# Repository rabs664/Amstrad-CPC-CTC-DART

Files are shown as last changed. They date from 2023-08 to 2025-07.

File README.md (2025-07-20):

# Amstrad CPC CTC DART
Simple Z80 CTC and DART board compatible with the Amstrad CPC and MX4 connector

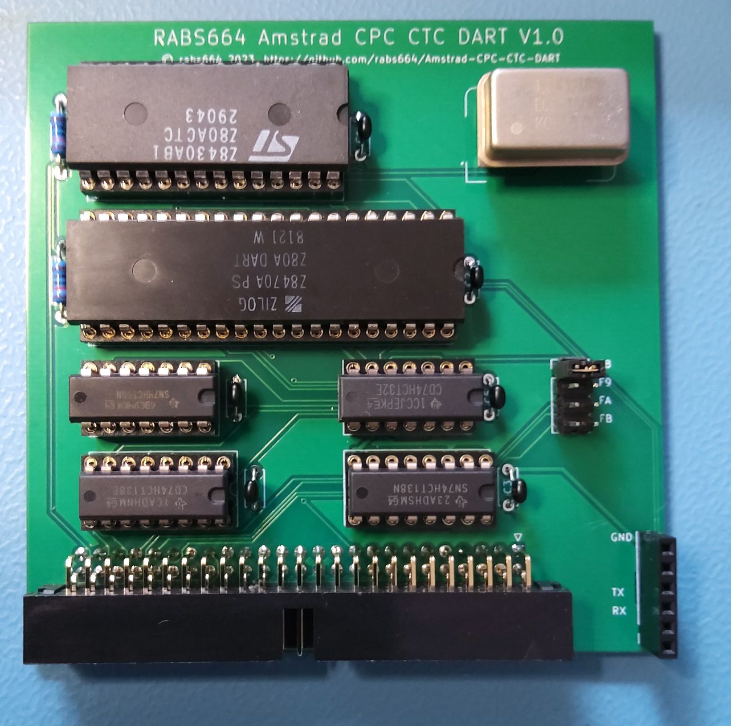
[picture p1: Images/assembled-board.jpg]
assembled-board


## Objective
Prototyping board to learn about the Z80 CTC and DART, and how to write Z80 assembly using an Amstrad CPC.

## Background
Part of a number of modular cards using Z80 associated peripherals and the Amstrad CPC.

See also;
[Amstrad CPC 2855 PIO](https://github.com/rabs664/Amstrad-CPC-8255-PIO), [Amstrad CPC Z80 CTC](https://github.com/rabs664/Amstrad-CPC-Z80-CTC) and [Amstrad CPC Z80 DART](https://github.com/rabs664/Amstrad-CPC-Z80-DART)

## Backplane
[CPC Amstrad Expansion Backplane by revaldinho](https://github.com/revaldinho/cpc_ram_expansion/wiki/CPC-Expansion-Backplane)

## IO Addressing
The IO Address can be selected using jumpers, supporting the following base address.

* F8XX
* F9XX
* FAXX
* FBXX

The CTC is then adressed at XXEO and the DART at XXF0.

See [CPC Wiki IO Port Summary](https://www.cpcwiki.eu/index.php/I/O_Port_Summary) for a list of known IO ports used on the Amstrad CPC.

## Testing
The CTC DART board has been built and simple testing has been completed on an Amstrad CPC 6128.

Note also an FTDI Serial Adapter was used to connect to a Tera Term session.

## PCBs
PCBs are available from [Seeed Studio](https://www.seeedstudio.com/Amstrad-CPC-CTC-DART-V1-0-g-1398289).

## Components
This [Digi-Key](https://www.digikey.co.uk/en/mylists/list/81SQJULUKE) List contains all components excluding the Z80 CTC, DART and FTDI Serial Adapter.

## Assembler
[RASM](https://github.com/EdouardBERGE/rasm)

## Resources
[CPCWiki](https://www.cpcwiki.eu/index.php/Main_Page)

Z80 Application by James W Coffron ISBN 0-89588-094-6

## Acknowledgements
[@revaldinho](https://github.com/revaldinho)

Don Prefontaine 

Peter Murray

[@EdouardBERGE](https://github.com/EdouardBERGE)

[@johnwinans](https://github.com/johnwinans)

# Release History
## Version 1.0
* First Release

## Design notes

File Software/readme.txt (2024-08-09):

This folder contains software associated with the Amstrad CPC CTC DART.

* siolif01.asm contains function libary associated with the DART.
* siotst10.asm contains a test program in assembler
* siotst03.bas contains a simple test program in BASIC
* siotst07.bas contains a send an receive test program in BASIC
* siotst01.dsk disk file containing siotst03.bas and siotst07.bas

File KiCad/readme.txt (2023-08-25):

This folder contains files associated with the use of KiCad 7 to create the schematics and PCB.

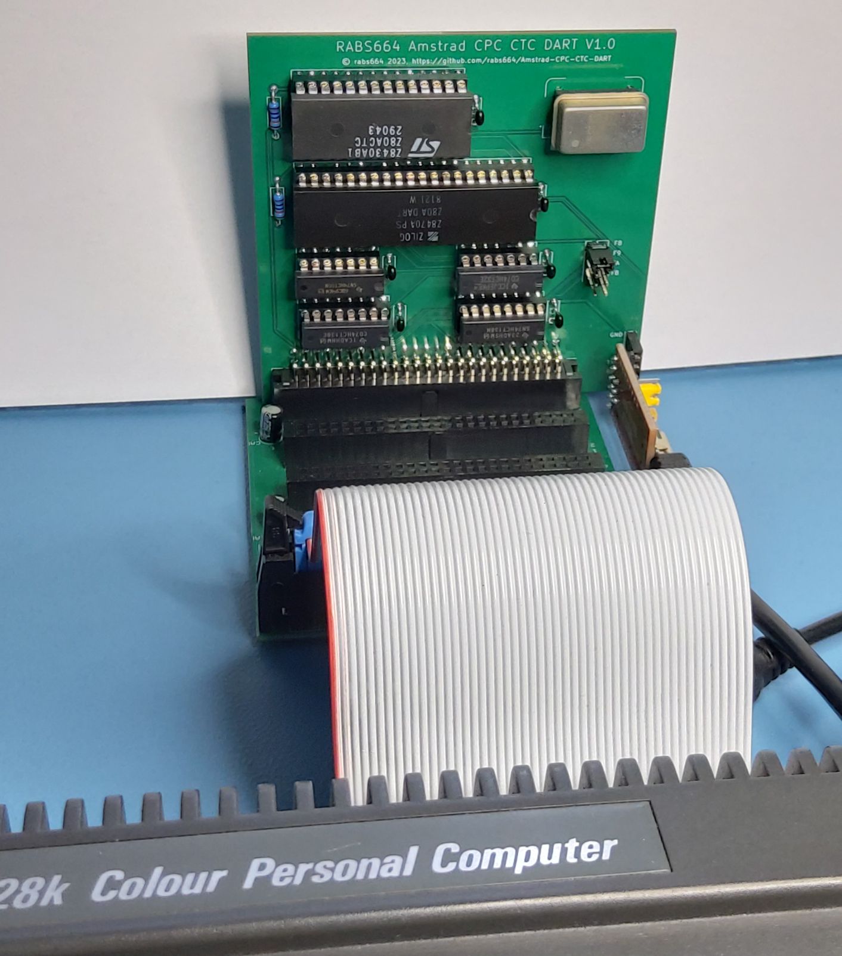
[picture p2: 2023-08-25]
Images/board-connected-CPC.jpg

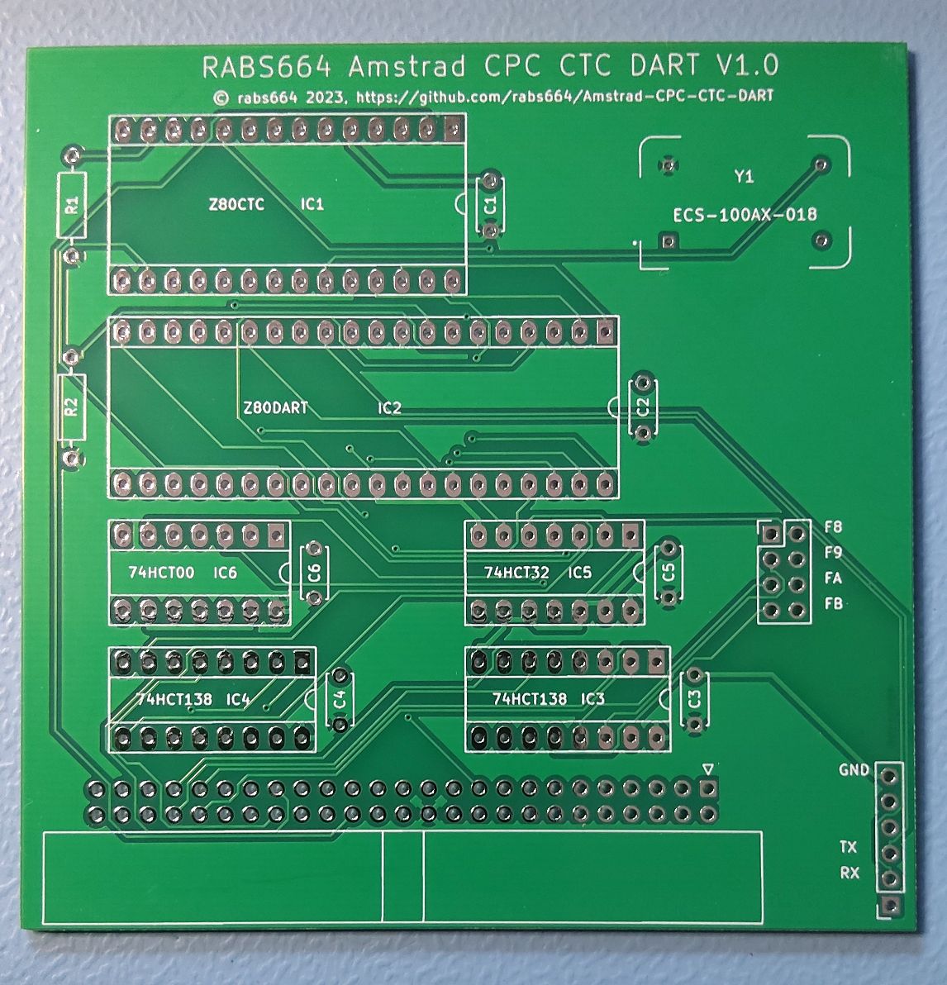
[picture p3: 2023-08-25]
Images/bare-board.jpg

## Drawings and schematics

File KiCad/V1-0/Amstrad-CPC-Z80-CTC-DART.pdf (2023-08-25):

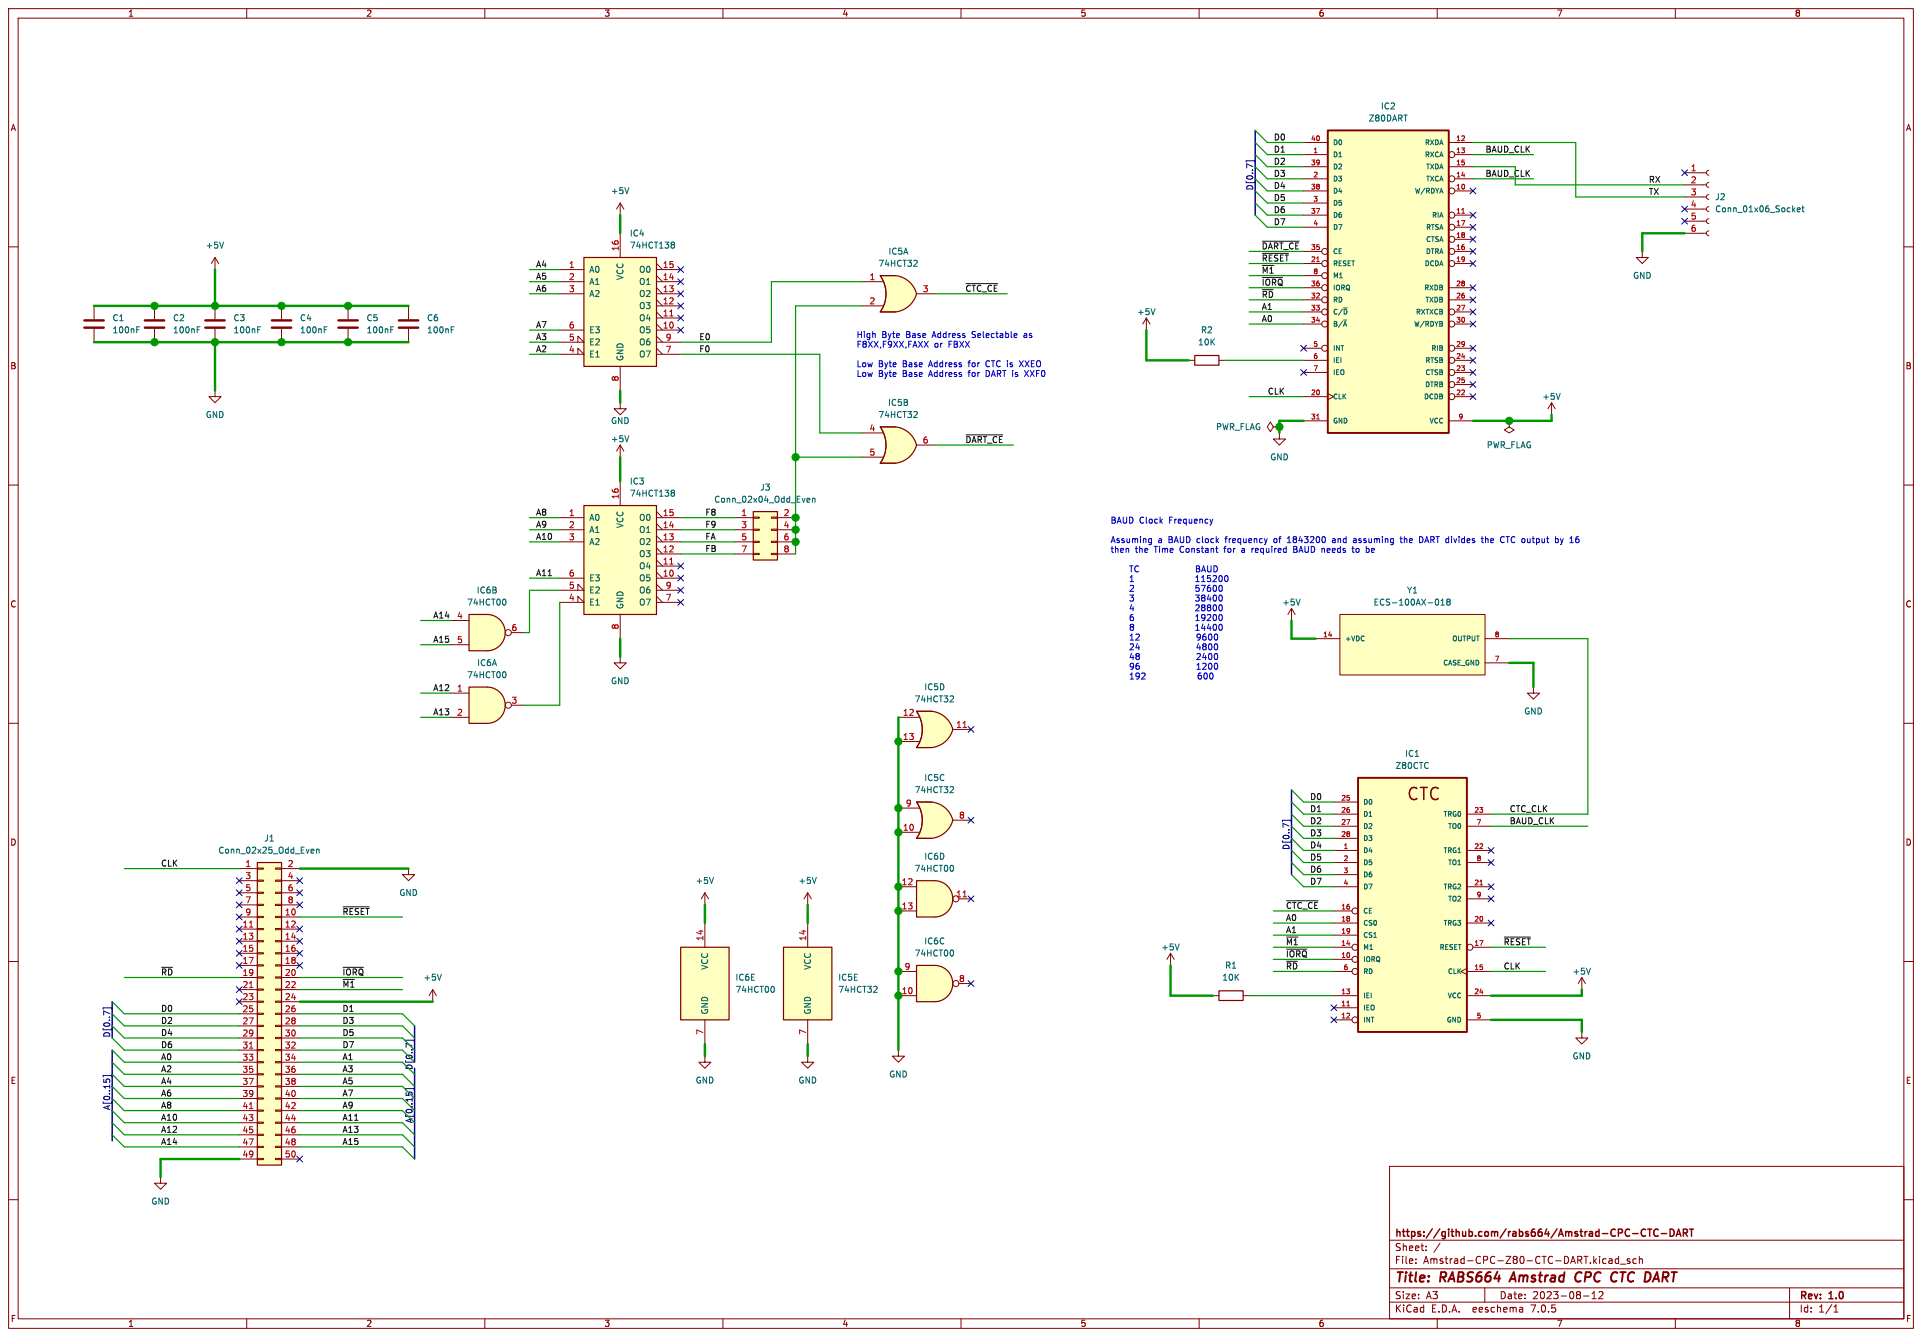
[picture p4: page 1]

Low Byte Base Address for CTC is XXEO

File: Amstrad-CPC-Z80-CTC-DART.kicad_sch Sheet: / https://github.com/rabs664/Amstrad-CPC-CTC-DART

Id: 1/1 Title: RABS664 Amstrad CPC CTC DART

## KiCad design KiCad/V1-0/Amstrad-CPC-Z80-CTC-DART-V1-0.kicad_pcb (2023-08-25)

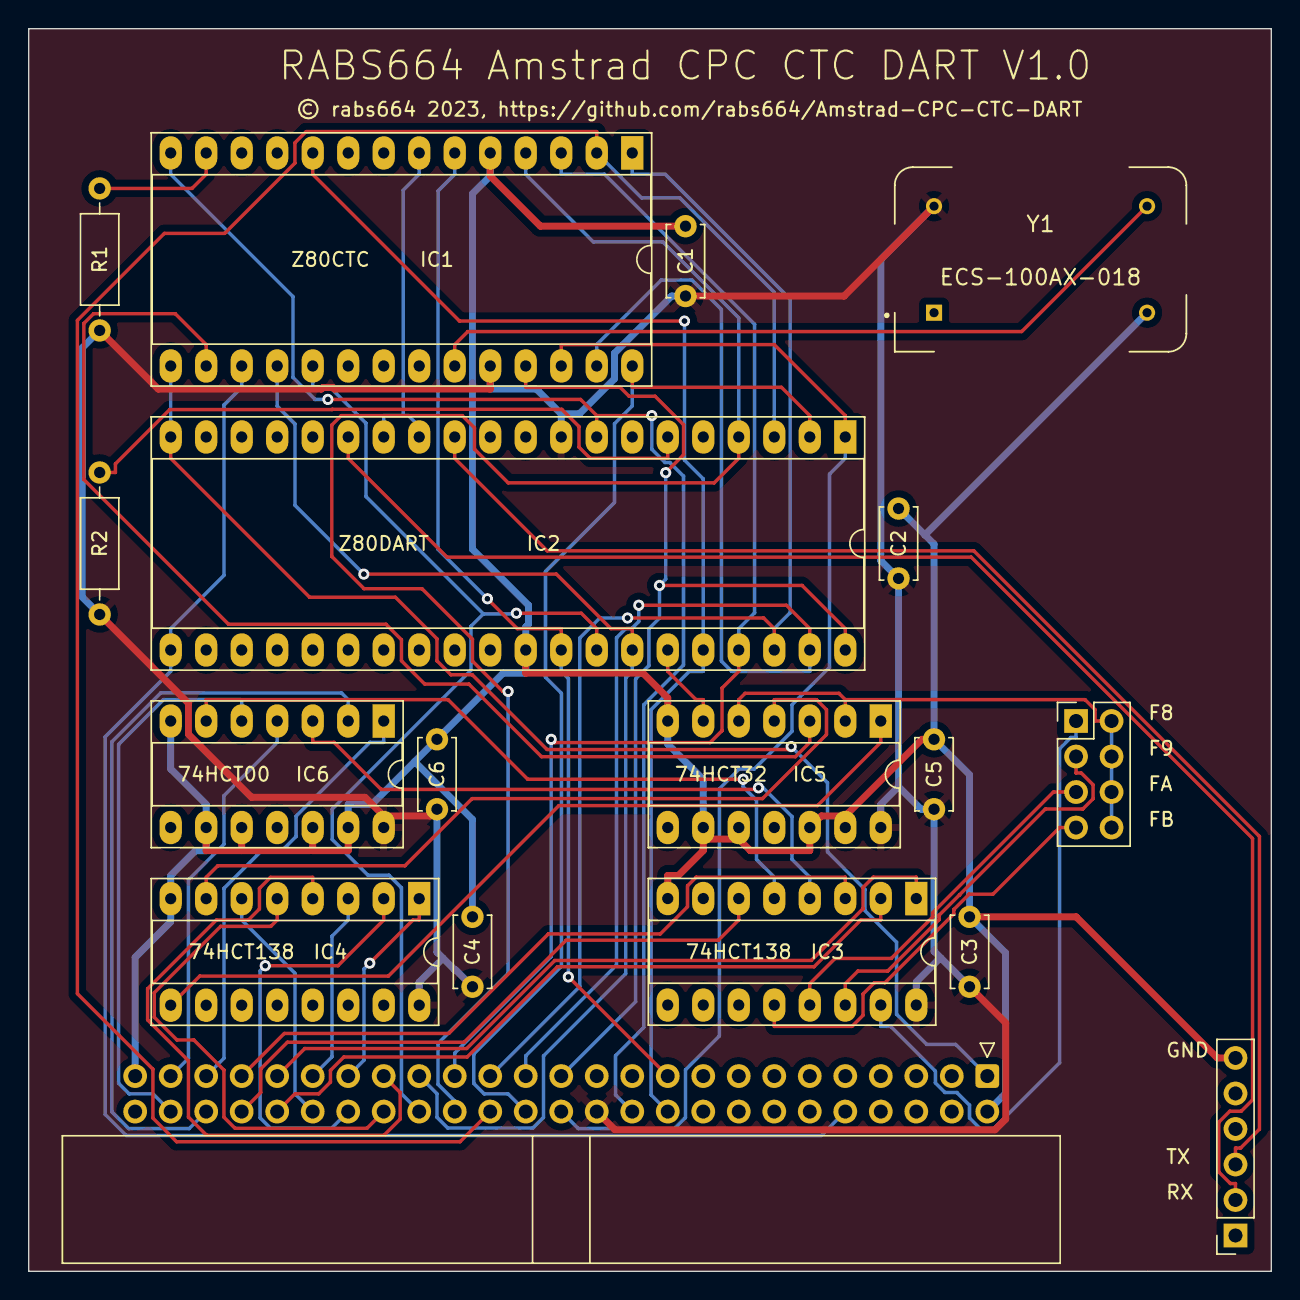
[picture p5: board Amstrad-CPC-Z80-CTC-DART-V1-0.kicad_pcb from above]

Board: 2 copper layers, 88.9 x 88.9 mm, 18 parts (0 on the bottom side), 48 nets.

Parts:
C1, C2, C3, C4, C5, C6: 100nF; C_Disc_D5.0mm_W2.5mm_P5.00mm
IC1: Z80CTC; DIP-28_W15.24mm_Socket_LongPads
IC2: Z80DART; DIP-40_W15.24mm_Socket_LongPads
IC3, IC4: 74HCT138; DIP-16_W7.62mm_Socket_LongPads
IC5: 74HCT32; DIP-14_W7.62mm_Socket_LongPads
IC6: 74HCT00; DIP-14_W7.62mm_Socket_LongPads
J1: Conn_02x25_Odd_Even; IDC-Header_2x25_P2.54mm_Horizontal
J2: Conn_01x06_Socket; PinSocket_1x06_P2.54mm_Vertical
J3: Conn_02x04_Odd_Even; PinHeader_2x04_P2.54mm_Vertical
R1, R2: 10K; R_Axial_DIN0207_L6.3mm_D2.5mm_P10.16mm_Horizontal
Y1: ECS-100AX-018; OSC_ECS-100AX-018

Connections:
+5V: C1.1, C2.1, C3.1, C4.1, C5.1, C6.1, IC1.24 (VCC), IC2.9 (VCC), IC3.16 (VCC), IC4.16 (VCC), IC5.14 (VCC), IC6.14 (VCC), J1.24, R1.1, R2.1, Y1.14 (+VDC)
/A0: IC1.18 (CS0), IC2.34 (B/~A), J1.33
/A1: IC1.19 (CS1), IC2.33 (C/~D), J1.34
/A2: IC4.4 (E1), J1.35
/A3: IC4.5 (E2), J1.36
/A4: IC4.1 (A0), J1.37
/A5: IC4.2 (A1), J1.38
/A6: IC4.3 (A2), J1.39
/A7: IC4.6 (E3), J1.40
/A8: IC3.1 (A0), J1.41
/A9: IC3.2 (A1), J1.42
/A10: IC3.3 (A2), J1.43
/A11: IC3.6 (E3), J1.44
/A12: IC6.1, J1.45
/A13: IC6.2, J1.46
/A14: IC6.4, J1.47
/A15: IC6.5, J1.48
/BAUD_CLK: IC1.7 (TO0), IC2.13 (RXCA), IC2.14 (TXCA)
/CLK: IC1.15 (CLK), IC2.20 (CLK), J1.1
/CTC_CLK: IC1.23 (TRG0), Y1.8 (OUTPUT)
/D0: IC1.25 (D0), IC2.40 (D0), J1.25
/D1: IC1.26 (D1), IC2.1 (D1), J1.26
/D2: IC1.27 (D2), IC2.39 (D2), J1.27
/D3: IC1.28 (D3), IC2.2 (D3), J1.28
/D4: IC1.1 (D4), IC2.38 (D4), J1.29
/D5: IC1.2 (D5), IC2.3 (D5), J1.30
/D6: IC1.3 (D6), IC2.37 (D6), J1.31
/D7: IC1.4 (D7), IC2.4 (D7), J1.32
/E0: IC4.9 (O6), IC5.1
/F0: IC4.7 (O7), IC5.4
/F8: IC3.15 (O0), J3.1
/F9: IC3.14 (O1), J3.3
/FA: IC3.13 (O2), J3.5
/FB: IC3.12 (O3), J3.7
/RX: IC2.15 (TXDA), J2.2
/TX: IC2.12 (RXDA), J2.3
/~CTC_CE: IC1.16 (CE), IC5.3
/~DART_CE: IC2.35 (CE), IC5.6
/~IORQ: IC1.10 (IORQ), IC2.36 (IORQ), J1.20
/~M1: IC1.14 (M1), IC2.8 (M1), J1.22
/~RD: IC1.6 (RD), IC2.32 (RD), J1.19
/~RESET: IC1.17 (RESET), IC2.21 (RESET), J1.10
GND: C1.2, C2.2, C3.2, C4.2, C5.2, C6.2, IC1.5 (GND), IC2.31 (GND), IC3.8 (GND), IC4.8 (GND), IC5.7 (GND), IC5.9, IC5.10, IC5.12, IC5.13, IC6.7 (GND), IC6.9, IC6.10, IC6.12, IC6.13, J1.2, J1.49, J2.6, Y1.7 (CASE_GND)
unnamed: IC1.13 (IEI), R1.2
unnamed: IC2.6 (IEI), R2.2
unnamed: IC3.4 (E1), IC6.3
unnamed: IC3.5 (E2), IC6.6
unnamed: IC5.2, IC5.5, J3.2, J3.4, J3.6, J3.8

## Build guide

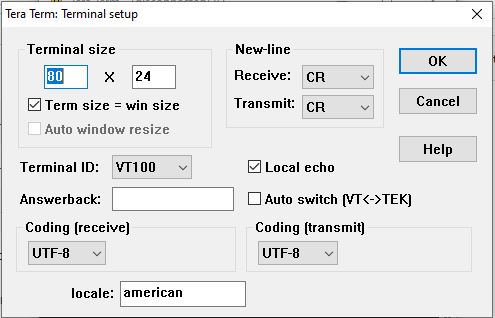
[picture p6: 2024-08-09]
Images/Tera-Term-Terminal-Setup.JPG

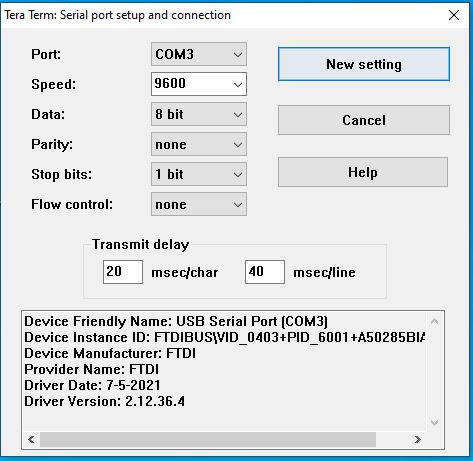
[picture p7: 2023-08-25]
Images/Tera-Term-Setup.JPG

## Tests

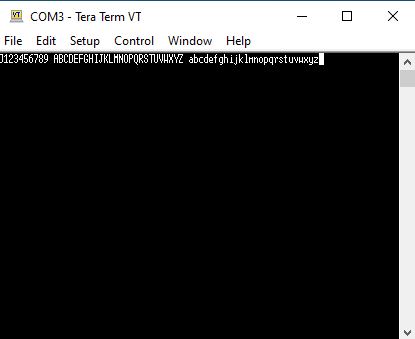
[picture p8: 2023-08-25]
Images/Tera-Term-Test-Output.JPG

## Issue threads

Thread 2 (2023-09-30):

Cannot get RTS/CTS flow control working.

rabs664, 2023-09-30:
V2.0 of the board was changed to support hardware flow control and so eliminate the need to add a delay between characters when transmitting to the board.

Unable to get RTS/CTS flow control working.

rabs664, 2023-09-30:
Basic problem is that the FTDI is unable to send a character to the DART unless WR5 Bit 1 RTS is set and then it appears flow control is actually disabled as RTS is always on. By that I mean characters are lost unless I add a delay between each character, see 20ms.

Currently setting WR3 Bit 5 Auto Enables.

RTS and CTS are crossed when connecting to the FDTI.

Description of WR3 Bit 5 Auto Enables in Z80 Applications by James W Coffron states;

"If this mode is selected DCD and CTS become the receiver and transmitter enables respectively. If this bit is not set DCD and CTS are simply inputs to their corresponding status bits in RRO."

So do I need to connect DCD to CTS on the FTDI?

rabs664, 2024-08-09:
Removed version 2.0 from repository.

rabs664, 2024-08-09:
Removed Version 2.0 from repository.

Closed 2024-08-09.

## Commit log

2023-08-25 Create KiCad
2024-08-09 Delete KiCad/V2-0 directory
    Version 2 hardware handshaking never worked
    [Amstrad-CPC-Z80-CTC-DART-V2-0.kicad_pcb, Amstrad-CPC-Z80-CTC-DART-V2-0.kicad_sch]

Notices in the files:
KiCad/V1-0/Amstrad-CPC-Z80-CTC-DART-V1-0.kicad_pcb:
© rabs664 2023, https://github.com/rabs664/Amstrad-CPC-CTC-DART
